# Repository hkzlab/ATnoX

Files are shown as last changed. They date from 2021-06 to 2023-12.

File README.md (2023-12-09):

# ATnoX

## Introduction

The ATnoX was born out of the necessity for me to have a small adapter adapter I could use to fit AT/XT motherboards into modern cases, powering them with ATX power supplies and turning them on with a momentary switch (the standard power on button present in computer cases built in the last 20+ years).

The [ATX2AT](https://x86.fr/atx2at-smart-converter/) is a wonderful device (I own several of them), but I prefer to use it to test my boards and then fall back onto a cheaper alternative I can close inside a case without it feeling like a waste.

In fact, the output connector uses the same pinout as the ATX2AT, but as I still had a free pin available, I decided to include a **TICK generator**: a 50/60hz square wave signal required by some big-box Amigas to turn on.

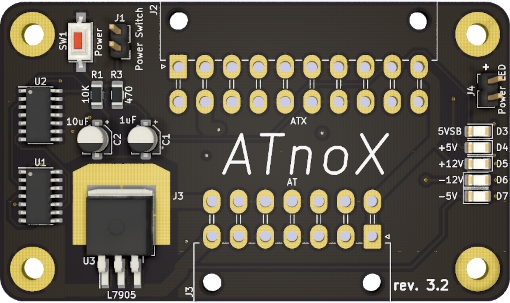
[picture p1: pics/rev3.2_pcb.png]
Rev. 3.2 PCB


## Pinout

14 pin connector, front view.

```text
                ____
.----.----.----|----|----.----.----.
| 14 | 13 | 12 | 11 | 10 |  9 |  8 |
|----+----+----+----+----+----+----|
|  7 |  6 |  5 |  4 |  3 |  2 |  1 |
'----'----'----'----'----'----'----'
```

1. +12V
2. +5V
3. +5V
4. GND
5. GND
6. TICK (50/60Hz depending on X1)
7. -5V
8. +12V
9. +5V
10. +5V
11. GND
12. GND
13. Power OK signal
14. -12V

## Component list

**TODO**

## Features

- -5v onboard generation via a 7905 regulator
- Momentary button power-on support
- Header for power led in case the motherboard lacks it
- Power on button included on board for bench testing
- Optional amiga Tick generator
- 4 Layer board (middle layers are +5v and GND)

## Credits

- logic-4000 libraries taken from [alexisvl/kicad-schlib](https://github.com/alexisvl/kicad-schlib)
- ATX power-on circuit taken from [skiselev/isa8_backplane](https://github.com/skiselev/isa8_backplane)
- Amiga Tick generator taken from [Aminet](http://aminet.net/package/docs/hard/Mix_and_Tick)
- Thanks to [@A-Small-Mice](https://github.com/A-Small-Mice) for the printable case

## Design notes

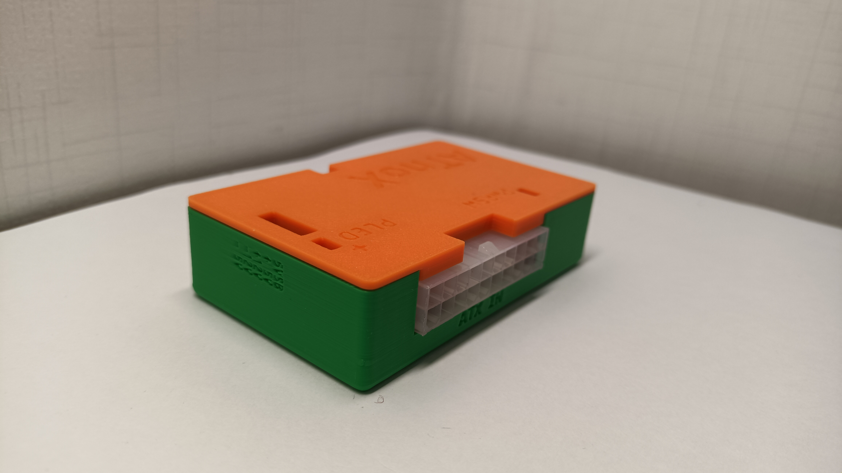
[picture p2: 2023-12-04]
3d_model/3d_model (2).jpg

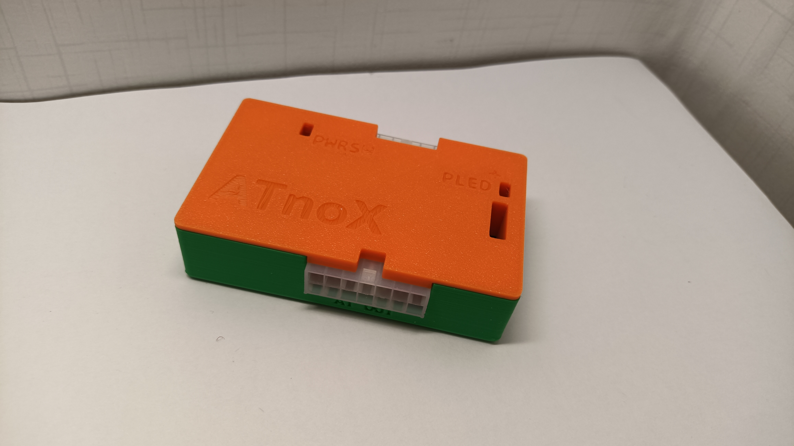
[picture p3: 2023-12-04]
3d_model/3d_model (1).jpg

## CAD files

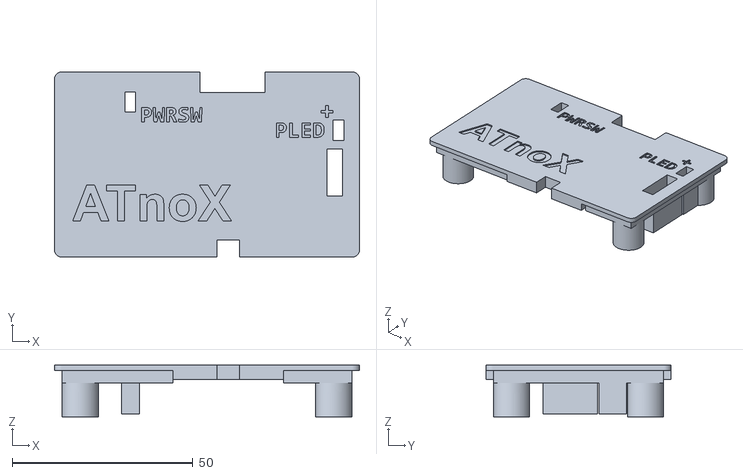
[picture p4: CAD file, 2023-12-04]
3d_model/ATnoX_Top.stl
84.3 x 51.2 x 14.3

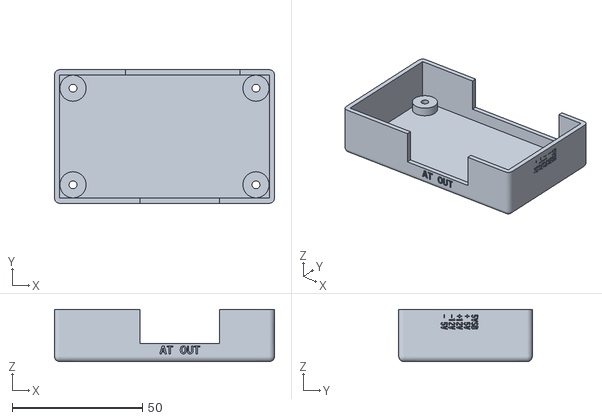
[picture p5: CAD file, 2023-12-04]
3d_model/ATnoX_Bottom.stl
84.3 x 51.2 x 20.0

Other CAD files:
3d_model/ATnoX_Case.f3d

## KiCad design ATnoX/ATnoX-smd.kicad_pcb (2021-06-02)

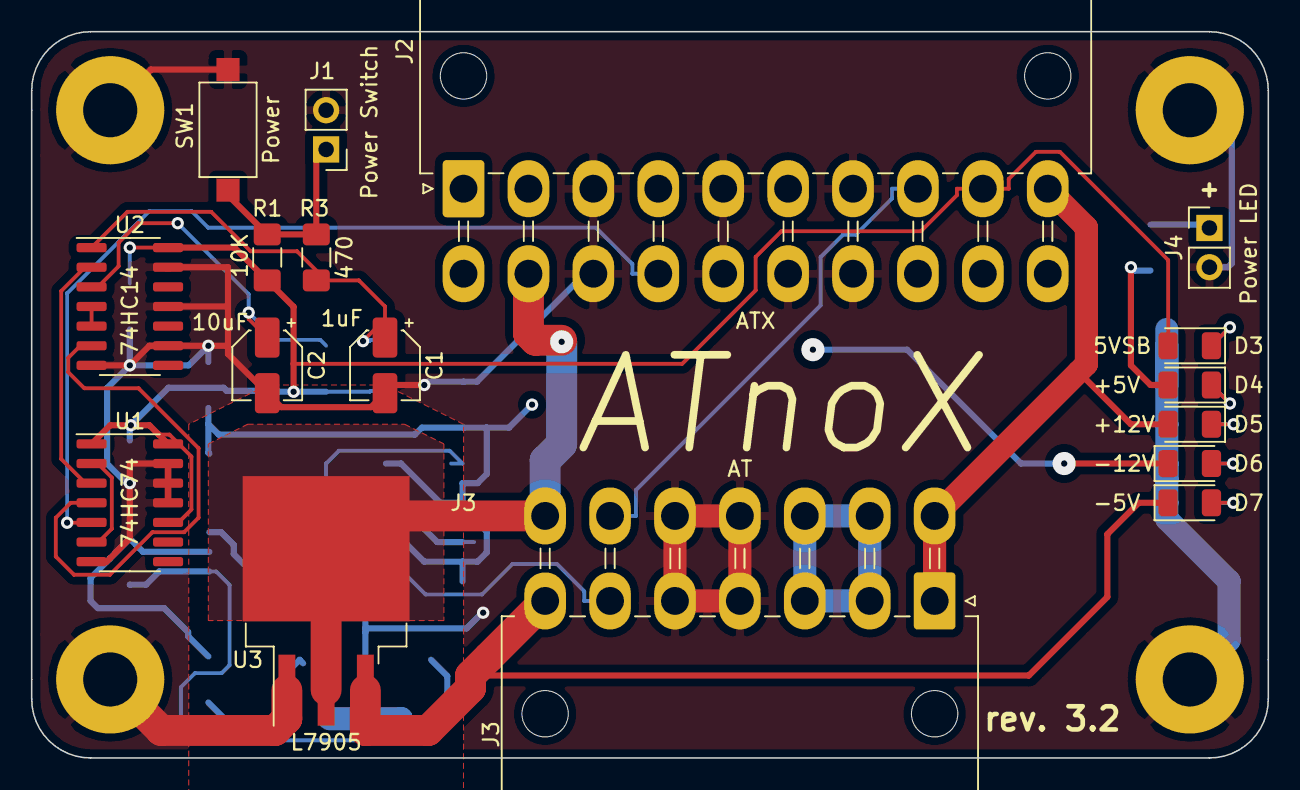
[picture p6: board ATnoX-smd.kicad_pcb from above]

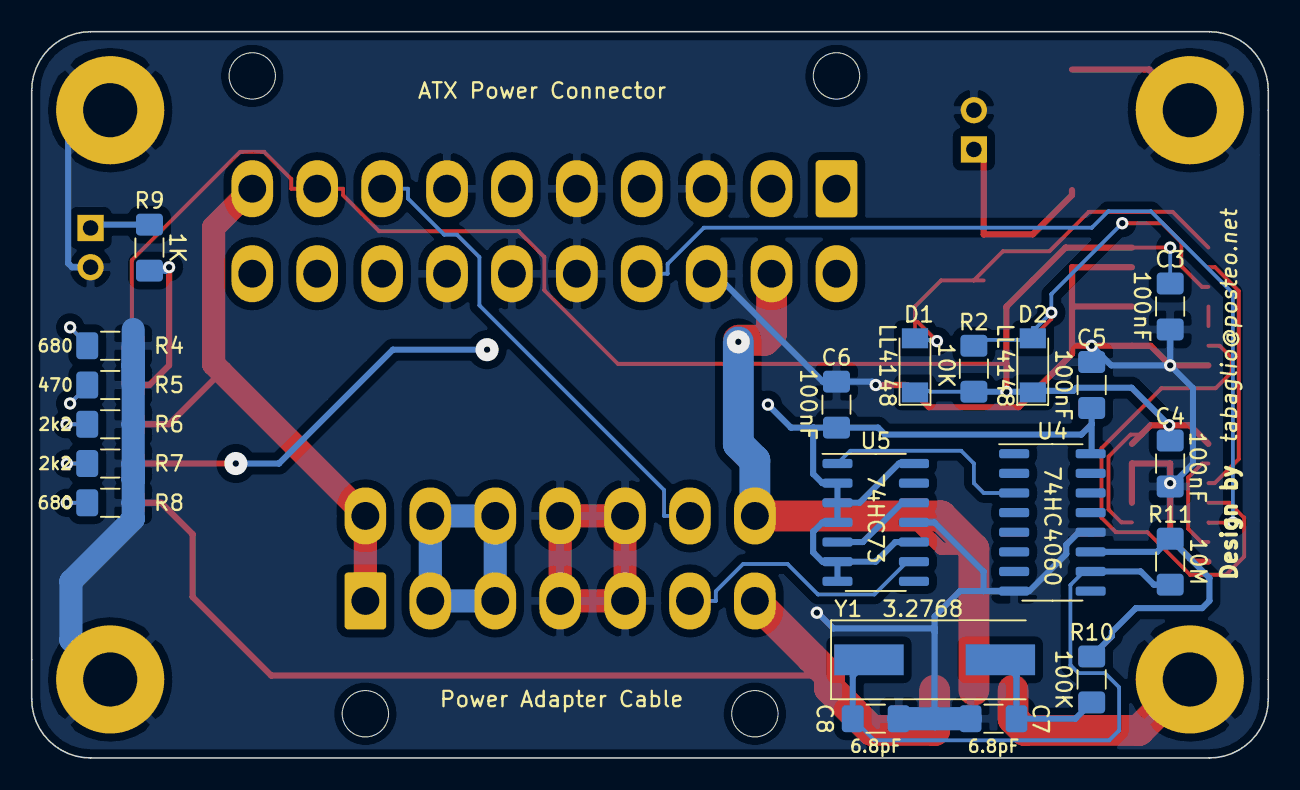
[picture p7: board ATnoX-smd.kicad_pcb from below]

Board: 4 copper layers, 80.0 x 47.0 mm, 41 parts (20 on the bottom side), 27 nets.

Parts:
C1: 1uF; CP_Elec_4x5.3
C2: 10uF; CP_Elec_4x5.3
C3, C4, C5, C6: 100nF; C_1206_3216Metric_Pad1.42x1.75mm_HandSolder
C7, C8: 6.8pF; C_1206_3216Metric_Pad1.42x1.75mm_HandSolder
D1, D2: LL4148; D_MiniMELF
D3: 5VSB; LED_1206_3216Metric
D4: +5V; LED_1206_3216Metric
D5: +12V; LED_1206_3216Metric
D6: -12V; LED_1206_3216Metric
D7: -5V; LED_1206_3216Metric
H1, H2, H3, H4: MountingHole_Pad; MountingHole_3.5mm_Pad
J1: Power Switch; PinHeader_1x02_P2.54mm_Vertical
J2: ATX; Molex_Mini-Fit_Jr_5569-20A2_2x10_P4.20mm_Horizontal
J3: AT; Molex_Mini-Fit_Jr_5569-14A2_2x07_P4.20mm_Horizontal
J4: Power LED; PinHeader_1x02_P2.54mm_Vertical
R1, R2: 10K; R_1206_3216Metric_Pad1.42x1.75mm_HandSolder
R3, R5: 470; R_1206_3216Metric_Pad1.42x1.75mm_HandSolder
R4, R8: 680; R_1206_3216Metric_Pad1.42x1.75mm_HandSolder
R6, R7: 2k2; R_1206_3216Metric_Pad1.42x1.75mm_HandSolder
R9: 1K; R_1206_3216Metric_Pad1.42x1.75mm_HandSolder
R10: 100K; R_1206_3216Metric_Pad1.42x1.75mm_HandSolder
R11: 10M; R_1206_3216Metric_Pad1.42x1.75mm_HandSolder
SW1: Power; SW_SPST_CK_RS282G05A3
U1: 74HC74; SOIC-14_3.9x8.7mm_P1.27mm
U2: 74HC14; SOIC-14_3.9x8.7mm_P1.27mm
U3: L7905; TO-263-3_TabPin2
U4: 74HC4060; SOIC-16_3.9x9.9mm_P1.27mm
U5: 74HC73; SOIC-14_3.9x8.7mm_P1.27mm
Y1: 3.2768; Crystal_SMD_HC49-SD

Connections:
/5VSB: C3.1, C4.1, D1.1, D2.1, D3.2, J2.9, R1.1, R2.1, U1.1, U1.10, U1.14, U2.14
/+12V: D5.2, J2.10, J3.1, J3.8
/-5V: D7.1, J3.7, U3.3
/-12V: D6.1, J2.12, J3.14, U3.2
/PWR_OK: J2.8, J3.13
/PWR_SW: J1.1, R1.2, R3.2, SW1.2
/TICK: J3.6, U5.9
/~PS_ON: J2.14, U1.5
GND: C1.2, C2.2, C3.2, C4.2, C5.1, C6.1, C7.2, C8.2, H1.1, H2.1, H3.1, H4.1, J1.2, J2.3, J2.5, J2.7, J2.13, J2.15, J2.16, J2.17, J3.4, J3.5, J3.11, J3.12, J4.2, R4.1, R5.1, R6.1, R7.1, R8.1, SW1.1, U1.7, U1.11, U1.12, U1.13, U2.7, U2.9, U2.11, U2.13, U3.1, U4.8, U4.12, U5.11
unnamed: C1.1, D1.2, R3.1, U2.1
unnamed: C2.1, D2.2, R2.2, U2.3
unnamed: C7.1, R10.2, Y1.2
unnamed: C8.1, R11.1, U4.10, Y1.1
unnamed: D3.1, R4.2
unnamed: D4.1, R5.2
unnamed: D5.1, R6.2
unnamed: D6.2, R7.2
unnamed: D7.2, R8.2
unnamed: J4.1, R9.2
unnamed: R10.1, R11.2, U4.11
unnamed: U1.2, U1.6
unnamed: U1.3, U2.2
unnamed: U1.4, U2.6
unnamed: U2.4, U2.5
unnamed: U4.3, U5.1
unnamed: U5.5, U5.12
VCC: C5.2, C6.2, D4.2, J2.4, J2.6, J2.19, J2.20, J3.2, J3.3, J3.9, J3.10, R9.1, U4.16, U5.2, U5.3, U5.4, U5.6, U5.7, U5.10, U5.14

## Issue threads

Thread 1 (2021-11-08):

How to produce? ...and possibly a screw or connection terminal as an alternative for AT cables

CKoewing, 2021-11-08:
Hi Fabio,

I think your ATnoX adapter is really great, just what I've been looking for for probably two weeks now. :-D

The only problem I have is that I am neither an electrician nor a PCB designer and I don't know how to produce a PCB from your Github repository at e.g. JLCPCB, PCBway, etc. Also, I can solder, but it stops with SMD components.

Can you tell me what I can do?

How about a revision 3.3 converted to through-hole components? ;-P

By the way, it would be great if instead of the 24-pin ATX-A-Like connector, I could alternatively solder on screw or connection terminals, so that I could simply cut off old AT cables, fit them with wire sleeves and screw them on.

Thanks and best regards,
Chris

hkzlab, 2021-11-08:
To produce the board you simply have to provide gerber files to the PCB Fab.
You can find already bundled gerbers inside the repository, here: https://github.com/hkzlab/ATnoX/tree/master/ATnoX/gerbers
Just use the latest zip and send it to the fab: usually the process is semi-automated via web interface E.g. https://cart.jlcpcb.com/quote

This project actually started as through-hole, but I did not like the size of the result. I currently don't have plans to do it, but if I ever get back to it and make a through hole version, it won't be in this repo, and will make a new project.

CKoewing, 2021-11-08:
Hi Fabio,

means I can't get around SMD soldering, right?

I had already uploaded the Gerber data to JLCPCB, but then I didn't really know which ticks to set for which options. Do you have any recommendations? Dos and don'ts?

Also JPCPCB offers to mount the components on a PCB, but this is currently only possible on one side.
And if I have seen this correctly, components are installed on both sides of your PCB. Right?

So what about a PCB revision 3.3 with the components installed on at least one side only, so that users like me could have the SMD components installed at JLCPCB?

This way you would also address a somewhat wider range of people with your great project. :-D

Sorry if I'm annoying you, I know computer hardware and software development, but I haven't had much to do with PCB's, except for very simple things using through-hole components.

Thank you very much in any case. :-)

hkzlab, 2021-11-08:
Exactly, in this case you can't get around it. None of the components on this board are fine pitched though, or require an especially steady hand.
JLCPCB offers the mounting of components at the fab, but it doesn't come "free": you need to provide files to match components to the footprints. Also, placing components on only one side of the board requires an extensive redesign, not to mention a significant increase in size of the board. I'm concentrated on other (unpublished, for now) projects in the very limited spare time I had these last months.

It would actually be a nice exercise for someone interested in learning KiCad: taking a relatively simple project like this and start rearranging components :wink: Not to mention I have not gotten around to add the BOM to the README yet, so you will have to open the project with kicad to get the exact values of the components for now.

The values autodetected by JLCPCB order module are fine. Just pay attention to layer ordering. See screenshot
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

CKoewing, 2021-11-08:
Ah, okay, so it is really a 4 layer PCB. Was thinking, that this is a fault of JLCPCB.

hkzlab, 2022-06-29:
Hello Chris!
Gave a very quick glance! Good job!
I'll have a more in-depth look as soon as I have some free time (a bit hectic), but I greatly appreciate whomever takes projects and adapts them for their own use :)

chris-kwng, 2022-07-01:
Now including a useful readme. 🙂

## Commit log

2019-11-22 Add Kicad project
    [ATlessX.kicad_pcb, ATlessX.sch]
2019-11-22 More of the circuit done
    [ATlessX.sch]
2019-11-23 Update schematic
    [ATlessX.sch]
2019-11-23 Add power leds
    [ATlessX.sch]
2019-11-23 First draft of the schematic
    [ATlessX.sch]
2019-11-23 Fix error
    [ATlessX.sch]
2019-11-24 Add some footprints
    [ATlessX.sch]
2019-11-24 Add footprintd
    [ATlessX.sch]
2019-11-24 Change footprints
    [ATlessX.kicad_pcb, ATlessX.sch]
2019-11-24 Update PCB schematic
    [ATlessX.kicad_pcb]
2019-11-24 Add filter caps
    [ATlessX.kicad_pcb, ATlessX.sch]
2019-11-24 Some more work
    [ATlessX.kicad_pcb]
2019-11-26 Design PCB
    [ATlessX.kicad_pcb, ATlessX.sch]
2019-11-26 Some Tweaks
    [ATlessX.kicad_pcb]
2019-11-28 Update PCB
    [ATlessX.kicad_pcb]
2020-01-25 Add gerbers
2020-02-04 Add SMD variant
    [ATnoX-smd.sch]
2020-02-04 Fix design, update gerbers
    [ATlessX.kicad_pcb, ATlessX.sch, ATnoX-smd.kicad_pcb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]
2020-02-05 Add ATLessX smd gerbers
2020-02-05 Better ATnoX PCB
    [ATnoX-smd.kicad_pcb]
2020-02-05 Add 2 layer version
    [ATnoX-smd-2la.kicad_pcb]
2020-02-05 Added better continuity between 5VSB and GND top/bottom
    [ATnoX-smd-2la.kicad_pcb]
2020-02-05 Update gerbers
2020-02-06 Add new revision of board
    [ATnoX-smd-2la.kicad_pcb]
2020-02-06 Add rev2 board
    [ATnoX-smd-2la.kicad_pcb]
2020-08-02 Turned the SMD version into a 4layer board
    [ATnoX-smd-2la.kicad_pcb, ATnoX-smd.kicad_pcb, ATnoX-smd.sch]
2020-09-01 Add rev. 2.5 of SMD variant
    [ATnoX-smd.kicad_pcb, ATnoX-smd.sch]
2020-09-01 Rev 3
    [ATnoX-smd.kicad_pcb, ATnoX-smd.sch]
2020-09-01 Clear a DRC issue
    [ATnoX-smd.kicad_pcb]
2020-09-01 Remove tracks ending in a no routing zone
    [ATnoX-smd.kicad_pcb]
2020-09-01 Add thermal relief pads
    [ATnoX-smd.kicad_pcb]
2020-09-01 Add gerbers for rev.3
2020-09-01 Update r3 gerbers
    [ATnoX-smd.kicad_pcb]
2020-09-01 Add silkscreen text
    [ATnoX-smd.kicad_pcb, ATnoX-smd.sch]
2020-09-02 Removed old versions, fix wrong pin connected to 4, rev 3.1
    [ATlessX.kicad_pcb, ATlessX.sch, ATnoX-smd.kicad_pcb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]
2020-09-02 Fix paths and update gerbers
    [ATnoX-smd.kicad_pcb]
2020-10-09 Begin adding some documentation to the project
    [ATnoX-smd.kicad_pcb, ATnoX-smd.sch]
2021-06-02 Add r3.2 gerbers
    [ATnoX-smd.kicad_pcb, ATnoX-smd.sch]
2021-06-02 slight adjustment to silkscreen
    [ATnoX-smd.kicad_pcb]
2021-11-09 Changed kicad url
2023-12-03 Add a 3D model for ATnoX
    [ATnoX_Bottom.stl, ATnoX_Case.f3d, ATnoX_Top.stl]
2023-12-09 Add credits for printable case
